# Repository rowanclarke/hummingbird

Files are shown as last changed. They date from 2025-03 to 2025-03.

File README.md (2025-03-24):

<div align="center">

# `hummingbird`

**A 30-key ergonomic keyboard.**

Top view

</div>

## Assembly

### Components

- [3.7V 300mAh 401030 Lithium Polymer Li-Po Rechargeable Battery](https://www.aliexpress.com/item/1005007586854504.html)
- [TENSTAR 2pcs NRF52840 Development Board](https://www.aliexpress.com/item/1005007738886550.html)
- [5PCS 1x40P 2.54mm Round Hole Female Header](https://www.aliexpress.com/item/10000000838267.html)
- [Kailh Hot Swap Socket for 1350 Chocolate Switches Low Profile](https://www.aliexpress.com/item/1005005449803412.html)
- [50PCS Mini 7-Pin On/Off 1P2T SPDT MSK-12C02 SMD Toggle Slide Switch](https://www.aliexpress.com/item/4000685483225.html)
- 5 x [6PCS Low Profile Keycaps For 1350 Chocolate Switch](https://www.aliexpress.com/item/1005005902080016.html)
- [30PCS Kailh Choc Low Profile Switch 1350 Chocolate Keyboard](https://www.aliexpress.com/item/1005005066585322.html)

**Optional**

- [1.5mm, M1.4 (OD2.3mm) Brass Insert](https://www.aliexpress.com/item/1005005776999972.html)
- [4mm M1.4 Black Stainless Steel Countersunk Head Screw](https://www.aliexpress.com/item/1005003116991205.html)
- [PORON Supper Soft Cotton Filling Mechanical Keyboard Bottom](https://www.aliexpress.com/item/1005004684031433.html)
- [100 Pcs/sheet Self Adhesive Buffer Bumper](https://www.aliexpress.com/item/1005003989623791.html)

### Equipment

- Soldering Iron
- Solder Wire
- Solder Flux Paste

**Optional**

- Craft Knife and Mat

### Processing

- PCB
  - Build keyboard: `cd ergogen && ergogen .` 
  - Add tracks: `sed -i ':a; $!{N; ba}; s/\(.*\))/\1'"$(sed -e ':a; N; $!ba; s/\n/\\n/g' -e 's/\&/\\&/g' tracks.scm)"\)'/' output/pcbs/hummingbird.kicad_pcb`
  - Build the tracks and zones:
    - Open `output/pcbs/hummingbird.kicad_pcb` in KiCad
    - Get the round-tracks plugin and round the tracks
    - Fill the ground zone with `B`
  - Plot `.gerber` files and drill files to `../gerber`
  - Zip: `zip hummingbird.zip output/gerber/hummingbird-*.{gbr,drl}`

- Case
  - Open `freecad/*.FCStd` in FreeCAD
  - Export each top-level mesh to STEP

### Manufacturing

- PCB - JLCPCB
  - Base Material: FR-4
  - Product Type: Industrial/Consumer electronics
  - Mark on PCB: Remove Mark
  - Layers: 2
  - PCB Qty: 5
  - PCB Thickness: 1.6mm

- Case - JLC3DP
  - 3D Technology: SLS(Nylon)
  - Material: 1172Pro Nylon
  - Colors: White

### Building

- Download [latest firmware](https://github.com/rowanclarke/kbd/actions/workflows/build.yml)
- Ground RST on the microcontroller twice within half a second to enter bootloader
- Mount microcontroller and copy the firmware to the device
- Reboot device and test
- Solder all components on the PCB
- Heat-set threaded inserts on cover plates
- Assemble
- Tape and cut out the PORON foam on the base plates

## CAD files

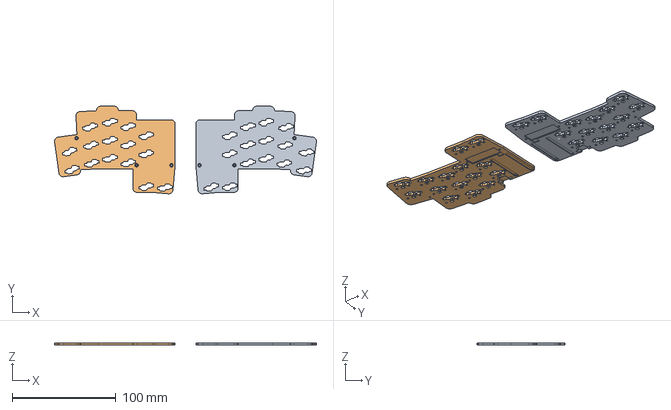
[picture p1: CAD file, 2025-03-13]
freecad/base.FCStd
252.4 x 84.5 x 2.00 mm
left
right

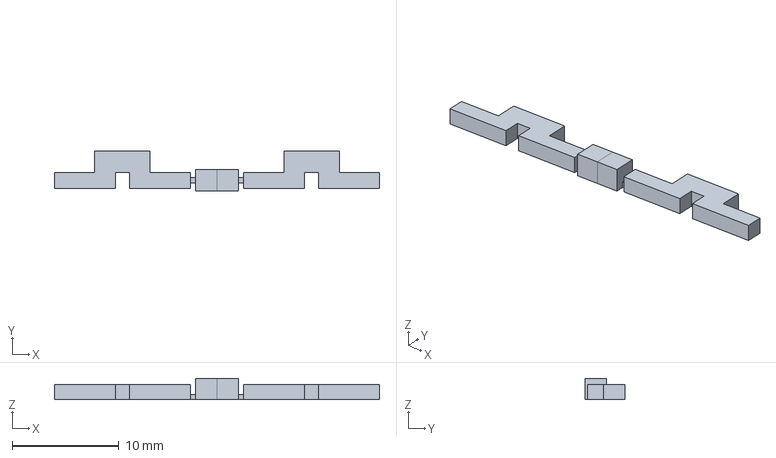
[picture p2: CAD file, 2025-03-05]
freecad/switch.FCStd
30.4 x 3.75 x 2.00 mm

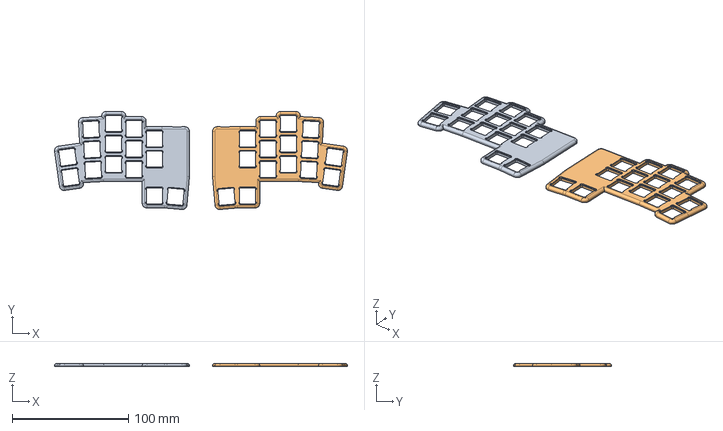
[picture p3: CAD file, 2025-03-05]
freecad/cover.FCStd
252.4 x 84.5 x 3.00 mm
left
right

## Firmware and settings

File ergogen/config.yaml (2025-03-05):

meta:
  engine: 4.1.0
units:
  ux: 17
  uy: 17
  ur: 2
  cx: 13.6
  cy: 13.6
  cr: 0.75
  e: 0.2
  p: 0.5
  m: 2
  kx: ux + p
  ky: uy + p
  pitch: 2.54
  mcu_width: 17.78
  mcu_height: 33.02
  mcu_padding: 2
  switch_width: 6.7
  switch_height: 2.7
  battery_width: 30
  battery_height: 10
  cover_depth: 2.2
  head_diameter: 3.2
  thread_diameter: 1.4
  insert_length: 1.5
  insert_diameter: 2.3
  pinky_stagger: ky/4
  pinky_spread: 2
  pinky_splay: 5
  sec_half_pinky_splay: 1.0009526851633
  cot_pinky_splay: 11.430052
  mounthole_dist: cot_pinky_splay * pinky_spread - pinky_stagger
  ring_spread: 0
  ring_splay: 3
  thumb_distance: 14
  reachy_splay: 5
  switch_cover_depth: 2
  switch_pin_depth: 1.5
points:
  rotate: pinky_splay + ring_splay
  key:
    width: ux
    height: uy
    spread: kx
    padding: ky
    autobind: 0
  zones:
    matrix:
      rows:
        bottom:
        home:
        top:
      columns:
        pinky:
        ring.key:
          stagger: ky + pinky_stagger
          spread: kx + pinky_spread
          splay: -pinky_splay
          origin: [-kx/2, -ky/2]      
        middle.key:
          stagger: ky/4
          spread: kx + ring_spread
          splay: -ring_splay
          origin: [-kx/2, -ky/2]
        index.key.stagger: -ky/4
        inner.key.stagger: -ky/2
        pinky.rows:
          top.net: "P15"
          home.net: "P5"
          bottom.skip: true
        ring.rows:
          top.net: "P18"
          home.net: "P14"
          bottom.net: "P6"
        middle.rows:
          top.net: "P19"
          home.net: "P16"
          bottom.net: "P7"
        index.rows:
          top.net: "P20"
          home.net: "P10"
          bottom.net: "P8"
        inner.rows:
          bottom.skip: true
          top.net: "P21"
          home.net: "P9"
        pinky.rows.top.bind: [0, kx, kx/2, 0]
        ring.key.bind: [0, kx/2, kx/2, 0]
        ring.rows.bottom.bind: [0, kx, 0, kx/2]
        middle.rows.home.bind: [kx/2, kx/2, kx/2, 0]
        index.rows.bottom.bind: [0, kx/2, 0, kx]
        index.rows.home.bind: [kx/2, kx/2, kx/2, 0]
        index.rows.top.bind: [0, 0, kx/2, kx/2]
        inner.rows.top.bind: [0, 0, 0, kx/2]
    thumb:
      anchor:
        ref: matrix_inner_bottom
        shift: [0, -thumb_distance]
      columns:
        tucky:
        reachy.key:
          stagger: 0
          splay: -5
          origin: [-kx/2, -ky/2]
        tucky.key.net: "P4"
        reachy.key.net: "P3"
        tucky.key.bind: [2ky, kx/2, 0, 0]
        reachy.key.bind: [0, 0, 0, kx/2]
    mcu:
      anchor:
        ref: matrix_inner_home
        shift: [ux/2 + mcu_width/2 + mcu_padding, 3uy/2 - mcu_height/2 + p]
      key:
        width: mcu_width
        height: mcu_height
        bind: [0, 0, 3ky/2, kx]
    switch.anchor:
      ref: matrix_inner_top
      shift: [0, ux/2 + m - (switch_cover_depth + switch_pin_depth + switch_height / 2)]
    battery.anchor:
      - aggregate.parts: [matrix_inner_home, thumb_tucky]
      - shift: [mcu_width/2 + mcu_padding/2, 0]
    battery_terminal.anchor:
      - ref: battery
        shift: [battery_width/2, battery_height/2]
      - shift: [-pitch/2, 3.73/2]
    mounthole_left.anchor:
      - aggregate.parts: [matrix_inner_home, thumb_tucky]
      - shift: [-ux/2 + head_diameter/2, 0]
    mounthole_right.anchor:
      - aggregate.parts: [matrix_inner_home, thumb_tucky]
        shift: [ux/2 + mcu_width + mcu_padding - head_diameter/2, 0]
    mounthole_pinky.anchor:
      - ref: matrix_pinky_home
        shift: [kx/2, -ky/2 - mounthole_dist]
        rotate: -pinky_splay/2
      - shift: [0, sec_half_pinky_splay * (2ky + mounthole_dist - head_diameter/2)]
outlines:
  mounthole:
    - what: circle
      radius: head_diameter/2 + e/2
      where:
        - /mounthole/
  insert:
    - what: circle
      radius: insert_diameter/2
      where:
        - /mounthole/
  switch:
    - what: rectangle
      size: [switch_width, switch_height]
      where: /switch/
  switch_plate:
    - what: rectangle
      size: [12.7, 1.5]
      adjust.shift: [0, switch_height/2 + switch_pin_depth/2]
      where: /switch/
    - what: rectangle
      size: [5.2, 2]
      adjust.shift: [0, switch_height/2 + switch_pin_depth + 1]
      where: /switch/
    - what: rectangle
      size: [1.3, 1.6]
      adjust.shift: [0, switch_height/2 + switch_pin_depth/2 - 0.05]
      where: /switch/
      operation: subtract
  switch_join:
    - what: rectangle
      size: 0.5
      adjust.shift: [-12.7/2 - 0.25, switch_height/2 + switch_pin_depth/2]
      where: /switch/
  switch_backbone:
    - what: rectangle
      size: 2
      adjust.shift: [-12.7/2 - 0.5 - 1, switch_height/2 + switch_pin_depth/2]
      where: /switch/
  _switch_zone:
    - what: rectangle
      size: [switch_width + 1.6, switch_height + 1.25]
      adjust.shift: [0, -1.25/2]
      where: /switch/
    - what: outline
      name: switch_plate
      adjust.shift: [-0.75, 0]
    - what: outline
      name: switch_plate
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

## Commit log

2024-05-25 Added Footprints
2024-06-05 Added Hotswap Switches
2024-06-05 Added Battery
    [hummingbird_routing.kicad_pcb]
2024-06-12 Reverse Battery
2024-06-14 Added On/Off Switches
    [hummingbird_routing.kicad_pcb]
2024-06-15 Added Mountholes
2024-06-15 Added Switch Via
2024-06-19 Added GND Via
2024-06-22 Added Clearance for Mountholes
2024-06-22 Custom Mountholes
2024-06-22 Added Pinky Mounthole
2024-07-29 Added Cover
    [cover.FCStd]
2024-10-22 Round PCB Corner
2025-01-30 Fixed Nets for Microcontroller
    [config.yaml]
2025-01-30 Added Battery Anchors
2025-01-30 Added Mounthole Outline
2025-01-30 Added Nets for Switch and Battery
2025-02-01 Added Custom Mask Footprint
2025-02-03 Added Battery Zone
2025-02-03 Track Width Clearance on Ground
2025-03-05 Added Key Bracket
2025-03-05 Added Base and Cover Plate Models
    [base.FCStd, cover.FCStd, switch.FCStd]
2025-03-13 Fixed Assymmetry for Hotswaps
    [base.FCStd]
